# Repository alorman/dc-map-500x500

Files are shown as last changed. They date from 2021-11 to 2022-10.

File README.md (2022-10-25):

# dc-map-500x500
This board requires the use of a backpack to operate. Currently the only developed backpack is [the ESP32 module](https://github.com/alorman/esp32-backpack).  

## Images
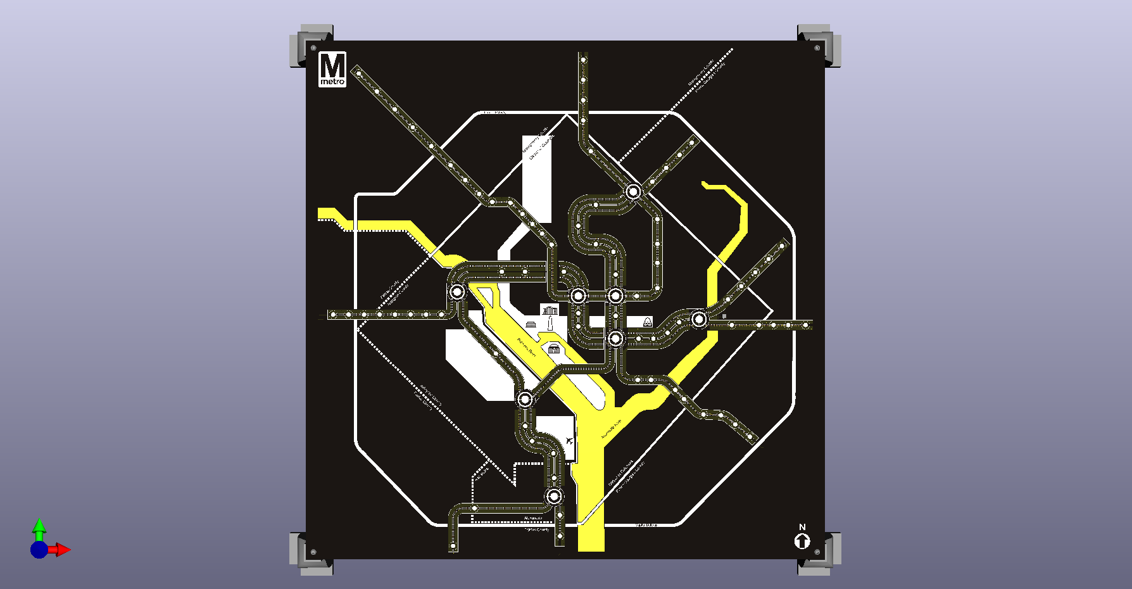
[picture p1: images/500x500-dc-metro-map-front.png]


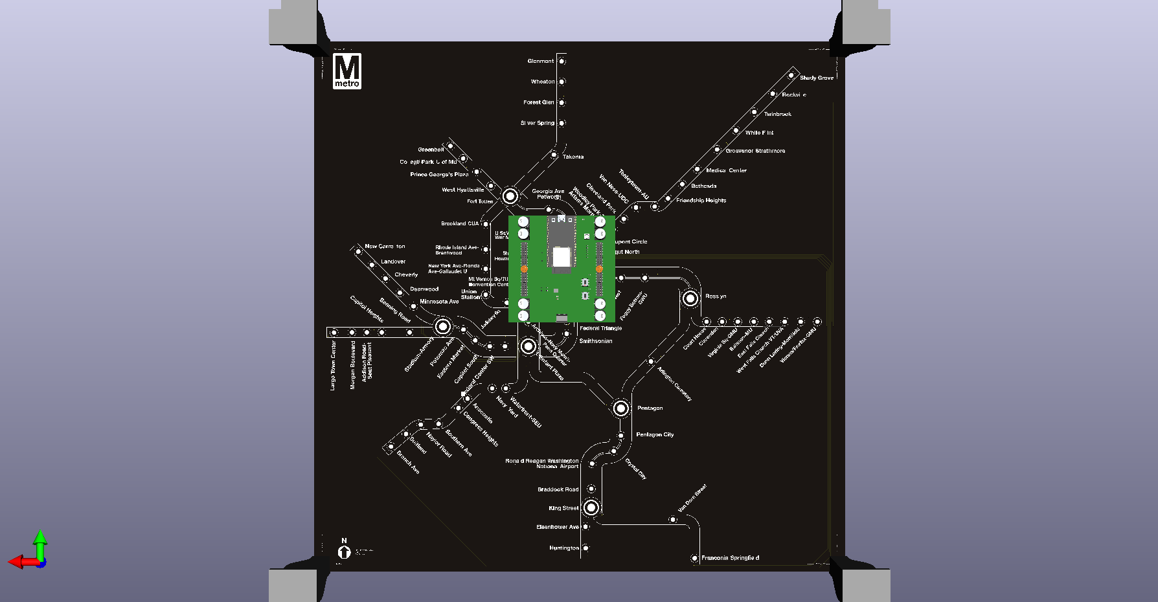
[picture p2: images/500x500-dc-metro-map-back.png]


## BOM
(no interactive BOM here, unfortunately)
| Qty  | MPN | Supplier | Reference | Value | Package | Type | Notes | Link |
|---|---|---|---|---|---|---|---|---|
| 1140 | SMD0805-0R | Any | LED1-LED1140 | | SK6805-1515 | SMD  | | http://www.normandled.com/upload/201903/SK6805-1515%20LED%20Datasheet.pdf |
| 1 | | | U1 | DNP | | | DNP | https://www.mouser.com/ProductDetail/Vishay-Semiconductors/VCNL4010-GS08?qs=s4XK1XdnRik7x1pyEKUO2w%3D%3D | |

## Pick and Place Files
[Pick and Place File](KiCad/500x500-dc-metro-map/PNP-Files/500x500-rev00-pnp.txt)

## Fab Instructions

| | |
|---|---:|
| Height (mm) | 500 |
| Width (mm) | 500 |
| Layers | 2 |
| Thickness (mm) | 1.6 |
| Solder Mask | Matte Black |
| Silkscreen | White |
| Copper Thickness  | 1 oz |
| Min Spacing | 6/6mil |
| Min Hole Size | 2mil |
| Via Process | Tented |
| Surface Treatment | HASL-Lead Free |
| Special Notes | See below |

## Special Fab Notes
This board is large, expensive and relies on pick-and-place assembly to get right. (I mean, you can TRY to solder 1,044 LEDs manually, but even doing 100 is a giant pain).

Since this board pushes the limits of most fab houses (just on size), it's worth reaching out to them by email to see if they can support. 

I can confirm the following fab houses can build this board.
| | Can Build Boards | Can Populate Boards |
|---|---|---|
| Elecrow | X | |
| AllPCB | X | X |
| PCBWay | X | X |
| PCBCart | X | X |
| JLCpcb | | |
| Seeeed Studio | X | X |
| Bittele | X | X |
| OurPCB | X | X |
| PCBonline | X | X |

Although their prices vary wildly.	

## LED Position Notes
| **ESP32 GPIO Number** | **Line Color** | **Number LEDs** |
|:---:|:---:|:---:|
| IO12 | Diagnostic | 1 |
| IO14 | Orange | 209 |
| IO27 | Yellow | 185 |
| IO26 | Green | 181 |
| IO25 | Blue | 298 |
| IO33 | Red | 267 |

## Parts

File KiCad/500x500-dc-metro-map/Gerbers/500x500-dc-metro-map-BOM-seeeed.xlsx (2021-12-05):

Designator | Manufacturer Part Number or Seeed SKU | QTY | Link
LED1-LED1140 | SK6805-1515 | 1140 | http://www.normandled.com/upload/201903/SK6805-1515%20LED%20Datasheet.pdf

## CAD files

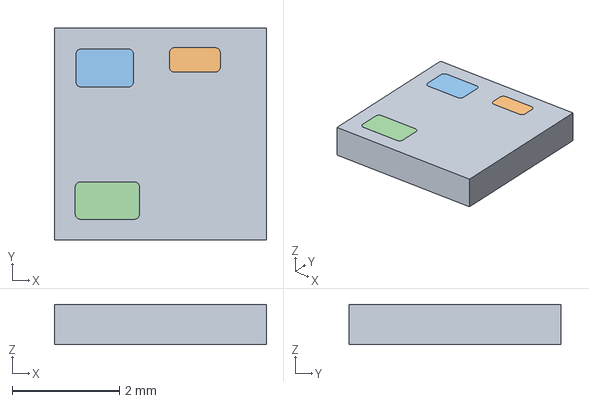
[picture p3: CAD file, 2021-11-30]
KiCad/_500x500-dc-metro-map-custom-libraries/VCNL4010.stp
3.95 x 3.95 x 0.75 mm

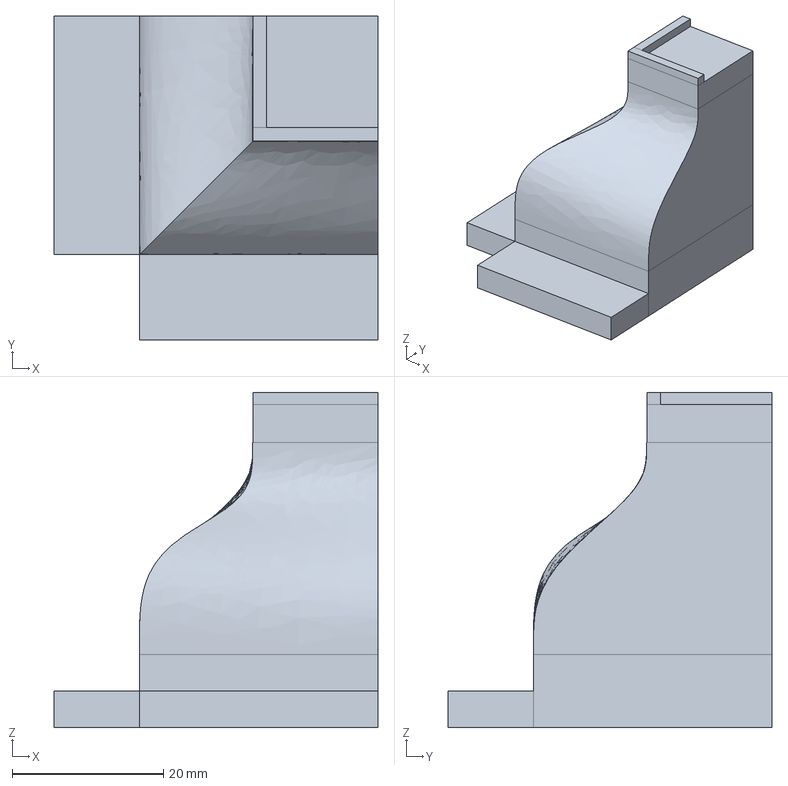
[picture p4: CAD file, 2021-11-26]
KiCad/_500x500-dc-metro-map-custom-libraries/frame mount rev00.stp
42.9 x 42.9 x 44.3 mm

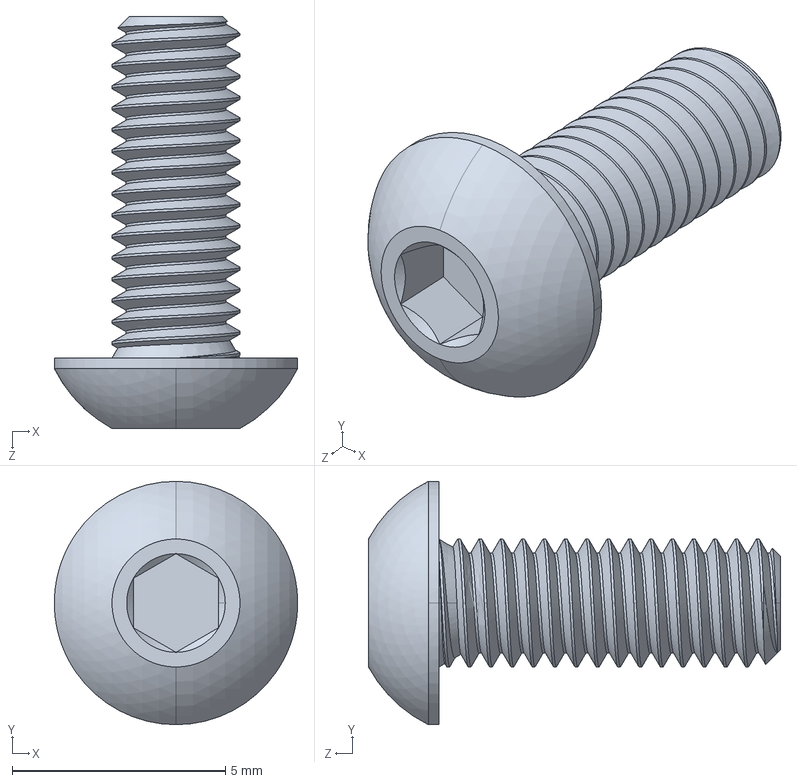
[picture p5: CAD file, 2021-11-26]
KiCad/_500x500-dc-metro-map-custom-libraries/91239A113_Button Head Hex Drive Screw.STEP
5.70 x 5.70 x 9.65 mm

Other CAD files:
Grasshopper-Scripting/EC10-block.3dm

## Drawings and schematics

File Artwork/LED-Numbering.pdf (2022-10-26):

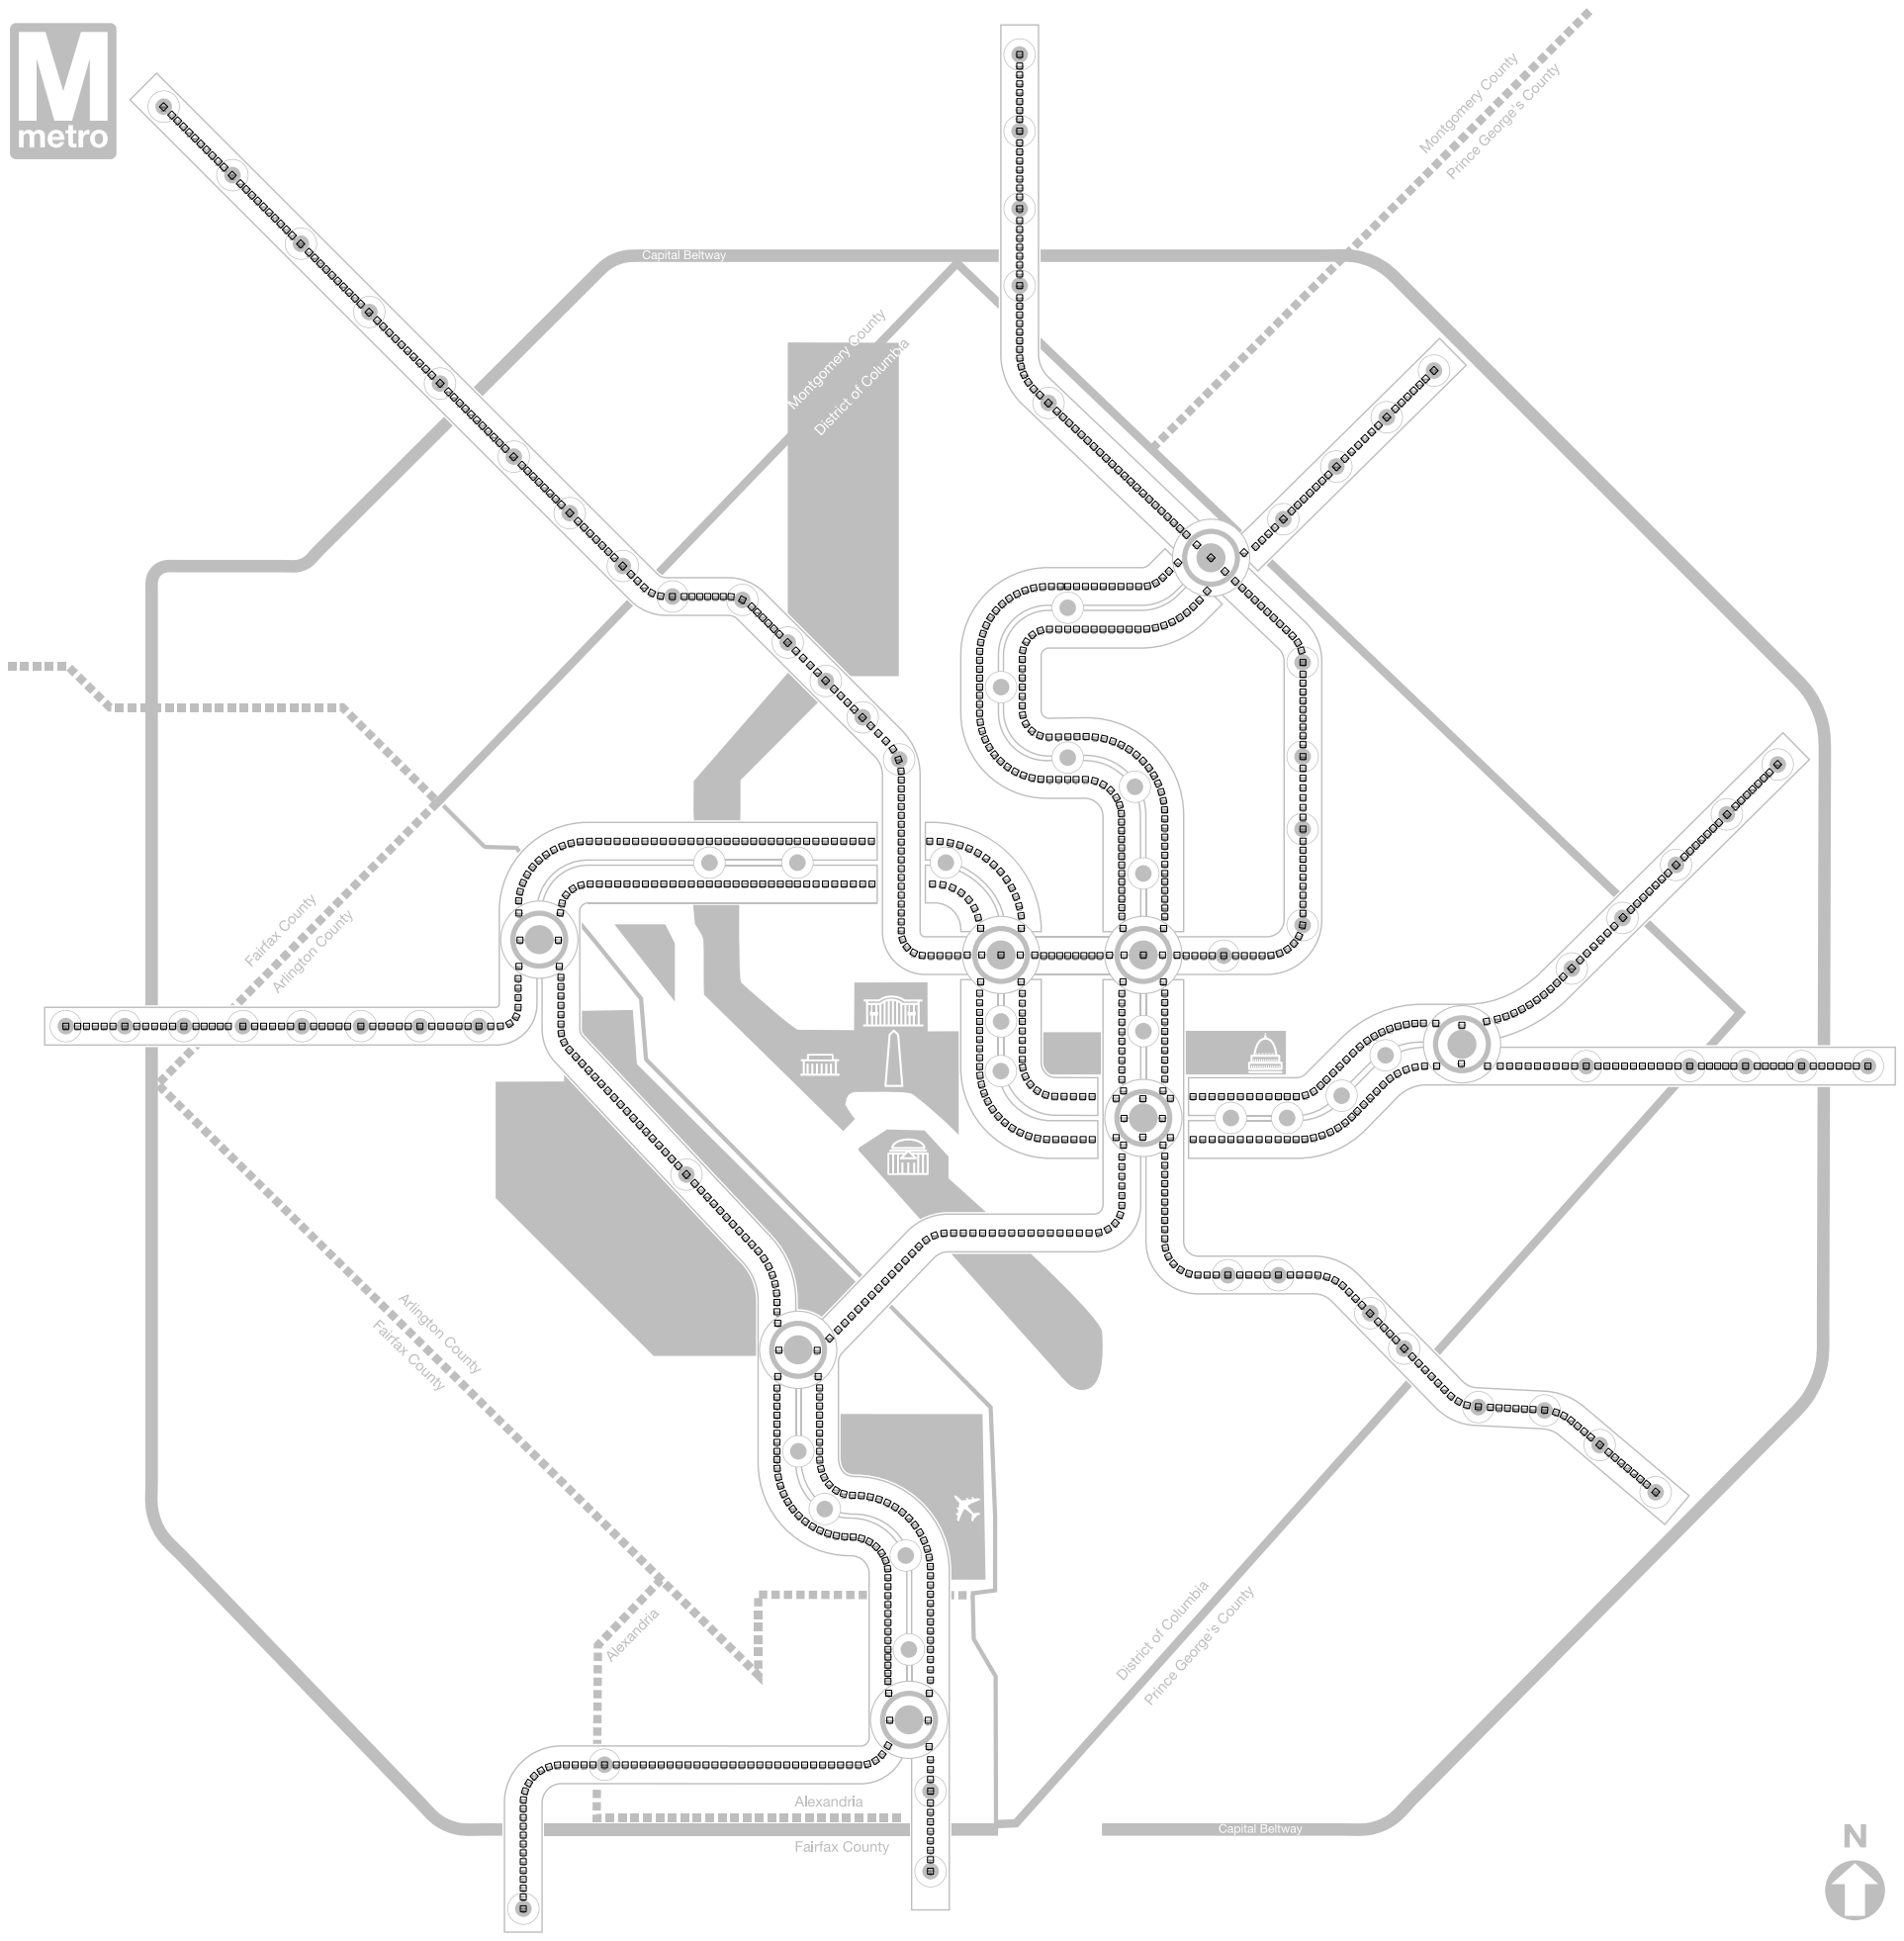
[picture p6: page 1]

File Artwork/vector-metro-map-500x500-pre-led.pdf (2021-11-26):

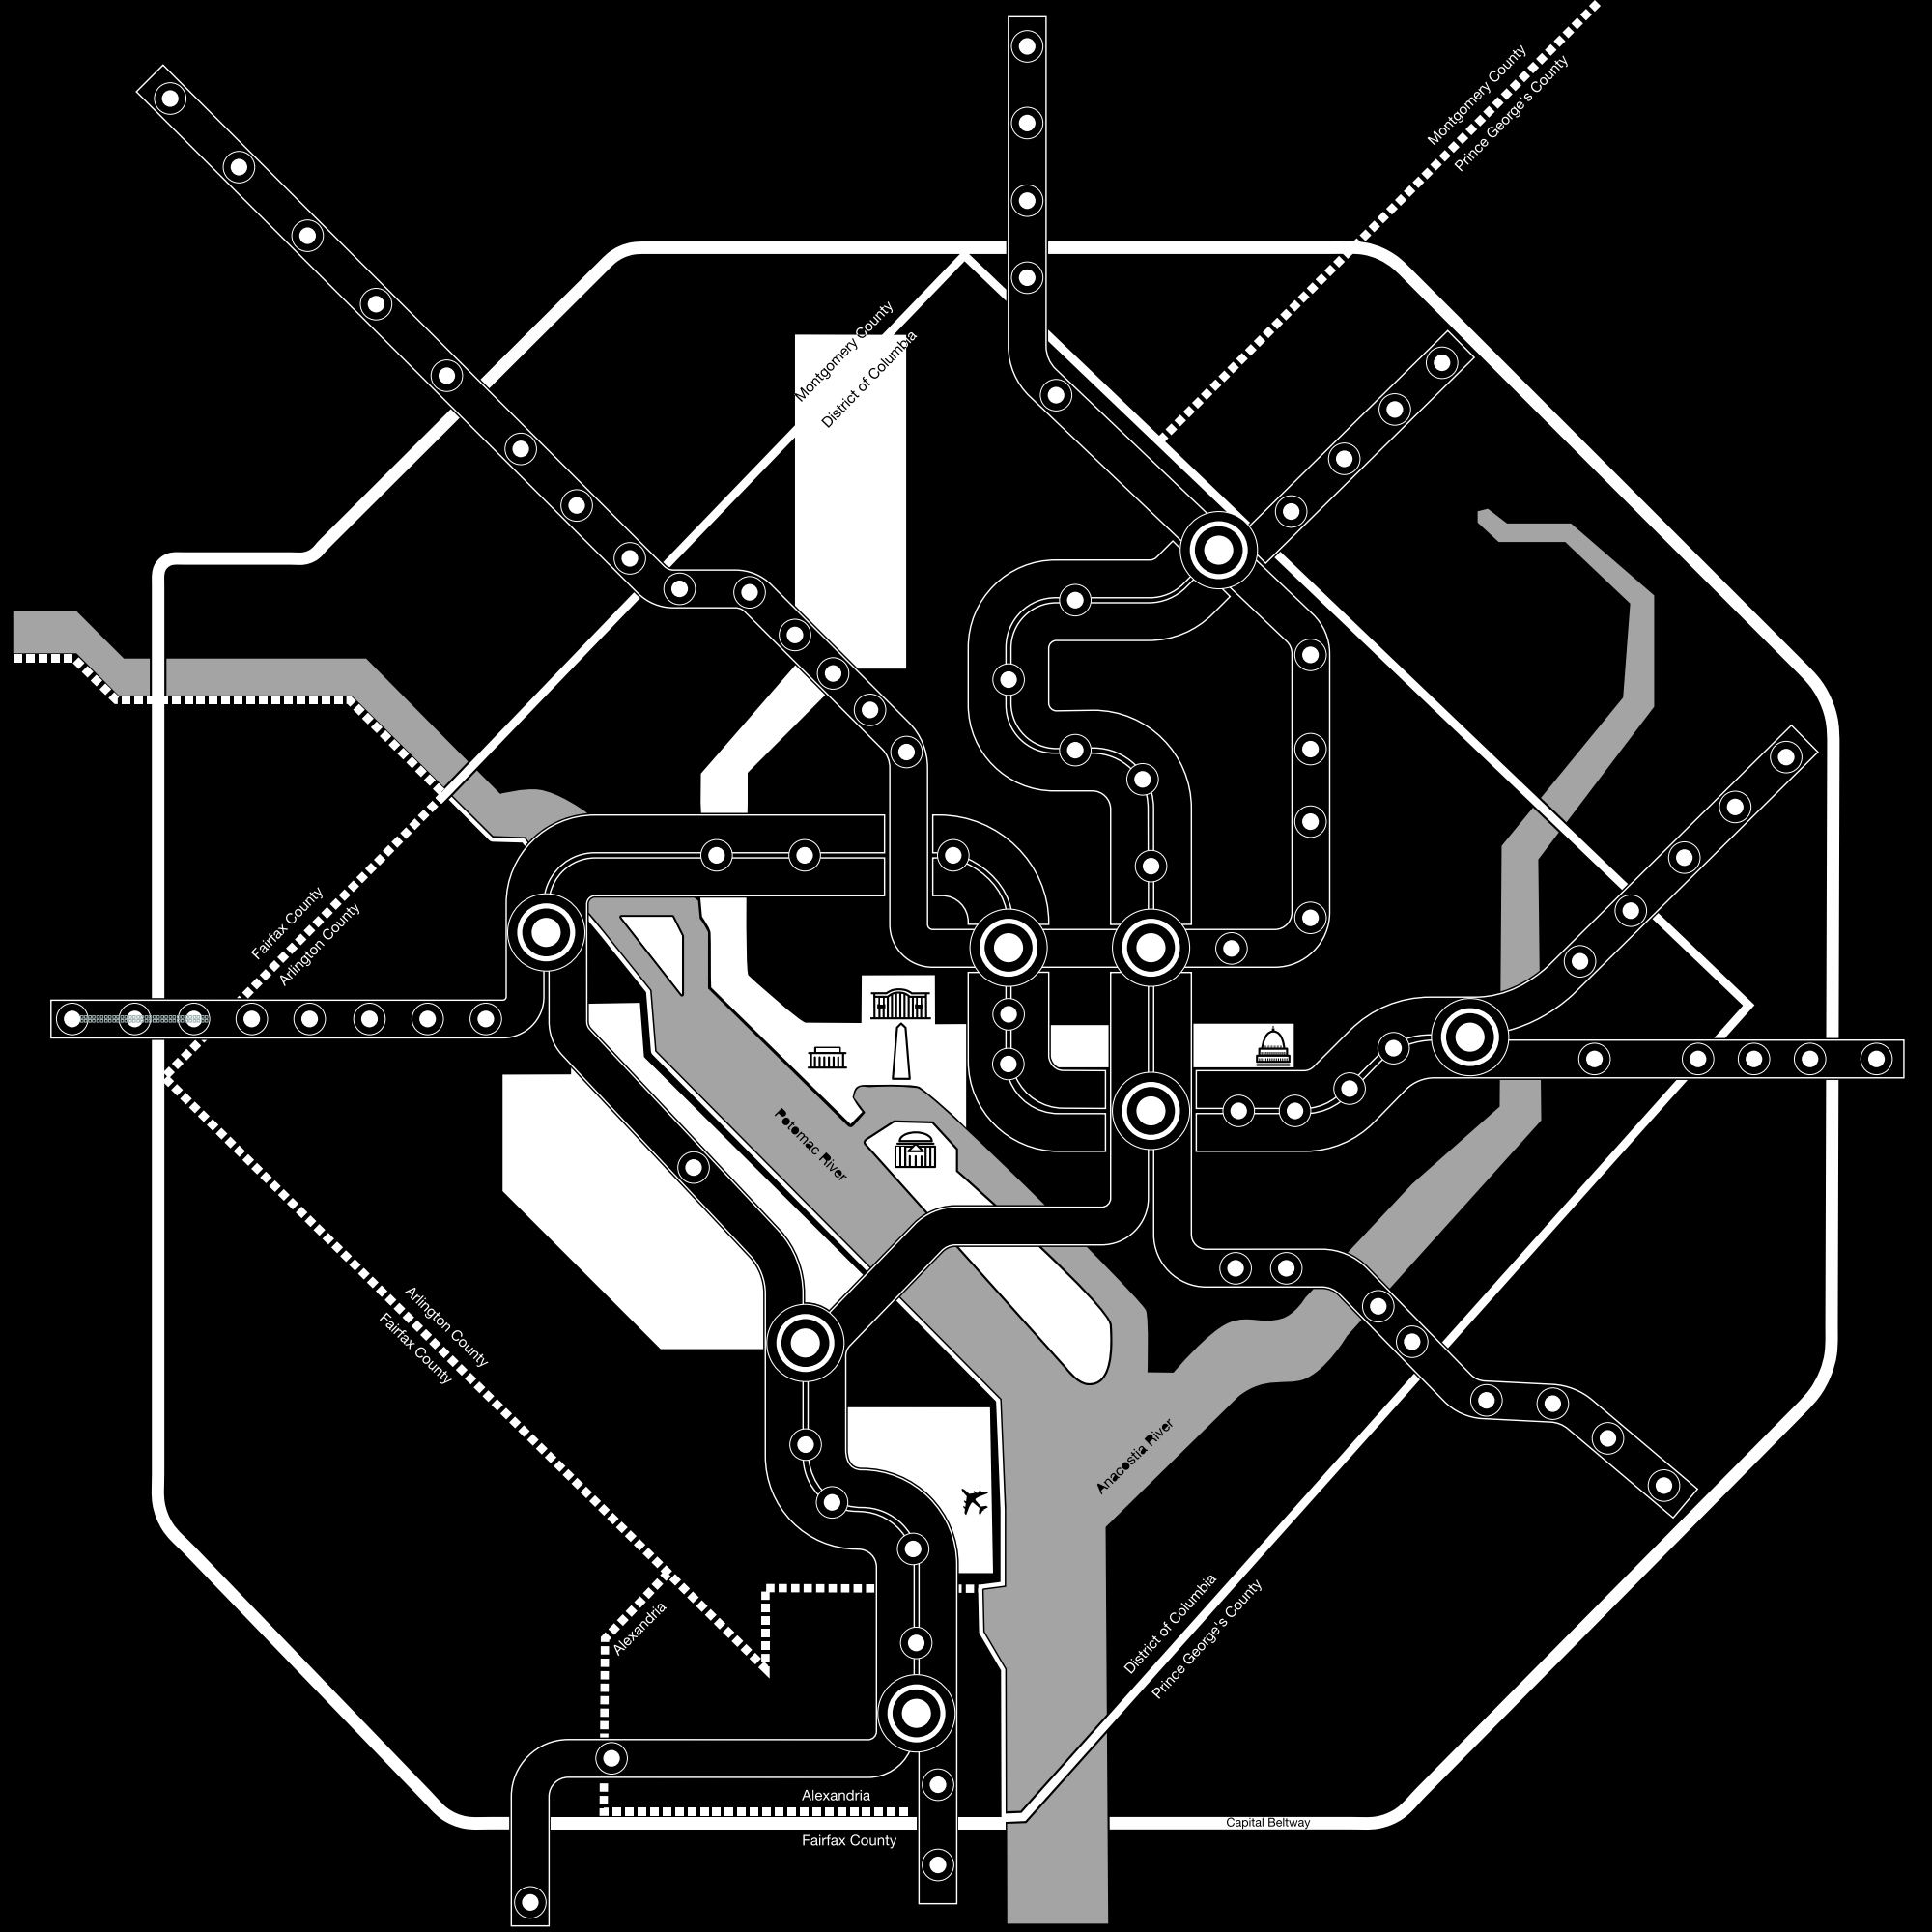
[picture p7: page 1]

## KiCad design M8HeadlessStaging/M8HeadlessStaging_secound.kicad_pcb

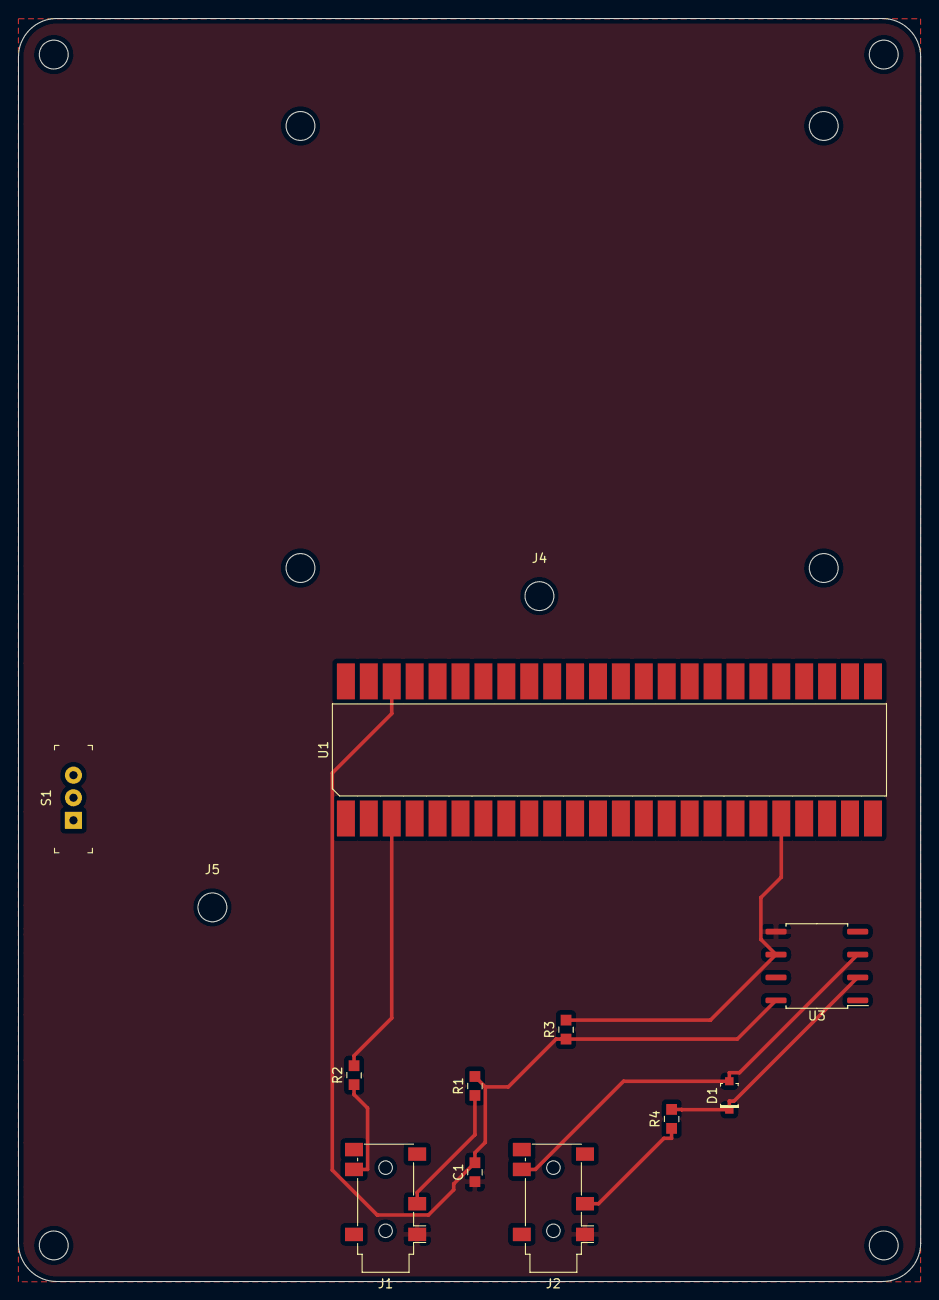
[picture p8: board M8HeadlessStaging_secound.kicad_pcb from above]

Board: 2 copper layers, 100.0 x 140.0 mm, 13 parts (0 on the bottom side), 11 nets.

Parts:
C1: 0.1uF; 0805
D1: 1n4148; SOD-123
J1: MIDI OUT; Jack_3.5mm_PJ311_Horizontal
J2: MIDI IN; Jack_3.5mm_PJ311_Horizontal
J4: TO_RASP_VIN; MountingHole_3.2mm_M3
J5: TO_BAT_MODULE; MountingHole_3.2mm_M3
R1, R2: 47R; 0805
R3: 470R; 0805
R4: 220R; 0805
S1: SLIDE_SWITCH; Switch_Slide_11.6x4mm_EG1218
U1: Teensy4.1; TEENSY4.1
U3: 6N138; SOP-8_6.62x9.15mm_P2.54mm

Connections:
+3V3: C1.2, R1.2, R3.1, U1.46, U3.8
GND: C1.1, J1.1, J2.1, U3.5
unnamed: D1.K, R4.2, U3.2
unnamed: D1.A, J2.4, U3.3
unnamed: J1.3, R1.1
unnamed: J1.4, R2.1
unnamed: J2.3, R4.1
unnamed: J4.1, S1.2
unnamed: J5.1, S1.1
RX1: R3.2, U1.20, U3.6
TX1: R2.2, U1.3

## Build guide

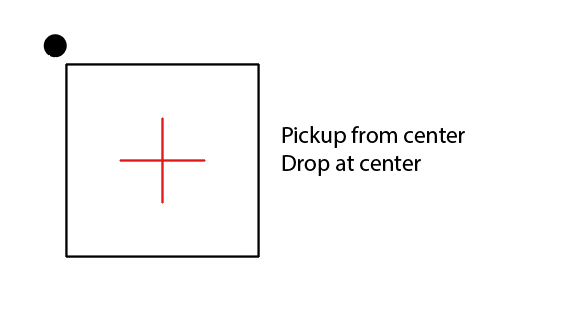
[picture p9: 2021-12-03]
KiCad/500x500-dc-metro-map/Gerbers/Rev01-allpcb/pickup instructions.PNG

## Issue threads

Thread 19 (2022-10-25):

LED Numbering sequence on lower right edge of Green line is reversed

alorman, 2022-10-25:

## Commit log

2021-11-26 add initial converstion of 500x500 board. commit all art
    [500x500-dc-metro-map.kicad_pcb, 500x500-dc-metro-map.sch]
2021-11-26 move WMATA logo, add mounting holes, edit mounting assembly
    [91239A113_Button Head Hex Drive Screw.STEP, frame mount rev00.stp]
2021-11-28 add working 500x500 board component
2021-11-28 Fix edge.cuts on 500x500 board, remove previous spurious routing
2021-11-30 add schematic, renumber pads, add proper netlist. set pad desigators
    [500x500-dc-metro-map.sch, VCNL4010.stp]
2021-12-02 add new power routing through zones rather than traces
2021-12-02 bugfixes, pad fixes, wiring of led starter nets
2021-12-03 add back silk graphics, both art and footprints
2021-12-03 commit beta 1 gerbers
    [500x500-dc-metro-map-BOM.csv, 500x500-dc-metro-map-BOM.xlsx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]
2021-12-05 via fix
    [500x500-dc-metro-map-BOM-seeeed.xlsx]
2021-12-17 add elecrow rev00 release, change file paths to relative for better portability, change libraries to relative, add globally unique library names
    [500x500-dc-metro-map-BOM.xlsx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]
2021-12-19 change paths to sort to top of list on open
    [91239A113_Button Head Hex Drive Screw.STEP, VCNL4010.stp, frame mount rev00.stp]
2021-12-22 update esp32 backpack to rev01 as fabbed
2022-01-04 update fab notes, change gerbers
    [500x500-dc-metro-map-BOM.xlsx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]
2022-01-07 fix !12 tags on holes
2022-01-14 rev to 01, fixing fill
    [500x500-dc-metro-map-BOM.csv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]
2022-10-25 update docs, unclear updates to kicad files
2022-10-26 add baked led numbering (ie R243) and PDF showing same
2022-10-26 update led numbering with "RD" vs "R" and set to base 0 instead of base 1
2025-09-12 starting EC10 rework
    [EC10-block.3dm]
